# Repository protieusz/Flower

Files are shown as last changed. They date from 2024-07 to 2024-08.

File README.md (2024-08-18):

# Flower

PCBWay sponsored Flower, a variant of Noraneko42W, willow layout with 36 keys &amp; interchangeable trackball size.

# Featured In

https://kbd.news/Flower-2440.html

# Sponsorship

Thank you PCBWay for sponsoring my Flower PCB.  For all you PCB needs, you can always rely on PCBWay for all your PCB prototypes. Superb PCBA quality PCBs. No issues or scratches. Customer service very helpful and friendly. I highly recommend PCBWay for all your PCB prototype needs.

# Detailed Summary

Flower is a heavily modified version of Noraneko42W which has been blessed by darakuneko himself for the mod. Noraneko42 was originally designed by [darakuneko](https://github.com/darakuneko/Noraneko/tree/main/noraneko42w).

A List Of Mods Made To The Original SVG by darakuneko:

-Eliminate the extra 6th columns on each sides.

-A square hole was created in the middle that can accomodate either a 34mm or 25mm trackball powered by PMW3360 sensor.

-Base of the trackball holder with lens cut out is integrated into the top case with integrated 5mm switch plate. Top case sits flush with pcb.

-Full keyboard case was created to house the PCB.

-Created 2 versions of the PCB. Version 1 does not have hot swap and solder switches straight to the pcb which is currently been sponsored. Version 2 has hot swappable Kailh and will not be printed or tested in the future so print at your own risk.

-Flower is powered by RP2040 Core - A which you can get from AE.

-QMK code is borrowed from aki27 bally and modified the matrix to fit my Flower. No suppport will be given since I just copy and paste.

-3DP trackball holder is designed by @ma_po_daisuki and his designs are being sold at [his Booth store](https://ma-po.booth.pm/items/5258743) which cost around $10 cad. Go check it out and support him.

-Or you can use my STL 34mm version that is include on the above.

-Use M2 brass hot inserts 3.2mm diameter and 4mm length for the M2 screws to secure the case. I forgot how long is my M2 screws are but they should be greater than 10mm so estimated around 14.6mm. Play around with and buy multiple M2 lenght screws.

# Full Production Pics
















A219904D-366C-4CD2-A794-261117A48990
CCFA0EC4-57FF-48DE-BFDE-543125D1833C
491BFB59-66FD-417E-A977-1B71E1DFDC40
C8178070-97BA-4DCF-92F3-48E1E20A30CD
E05B9192-131A-4184-A84B-3BD31019660E
F3263E68-312A-4EAE-A6C8-C606E3723F1F
15B827F9-AF45-4CA4-89C8-4C4626D03518
571AE4CF-D7C3-4529-B977-25B417AD6DEA

# Rendering

Screenshot_2024-07-08_at_12 00 05_PM
Screenshot_2024-07-09_at_8 46 44_AM
Screenshot_2024-07-09_at_8 46 56_AM
Screenshot_2024-07-09_at_8 47 13_AM
Screenshot_2024-07-09_at_8 47 26_AM






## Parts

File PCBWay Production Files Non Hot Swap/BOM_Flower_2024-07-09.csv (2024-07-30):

ID | Name | Designator | Footprint | Quantity | Manufacturer Part | Manufacturer | Supplier | Supplier Part | Price | link
1 | PRTR5V0U2X,215 | D11 | SOT-143_L2.9-W1.3-P1.92-LS2.3-BR | 1 | PRTR5V0U2X,215 | Nexperia(安世) | LCSC | C12333 | 0.089 | https://item.szlcsc.com/280548.html
2 | BSMD0805-020-15V | F1 | F0805 | 1 | BSMD0805-020-15V | BHFUSE(佰宏) | LCSC | C883103 | 0.043 | https://item.szlcsc.com/343298.html
3 | RP2040-Core-A | U1 | RP2040-CORE-A | 1 |  |  |  |  |  |  | Omit do not pick.
4 | PMW3360DM-T2QU | U11 | PMW3360DM-T2QU.PACK | 1 | PMW3360DM-T2QU |  |  |  |  | http://www.pixart.com/upload/PMS0058-PMW3360DM-T2QU-NNDS-R1.30-06042016_20160902201411.pdf |  | Omit do not pick.
5 | TYPE-C-31-M-12 | USBC1 | USB-C_SMD-TYPE-C-31-M-12 | 1 | TYPE-C-31-M-12 | 韩国韩荣 | LCSC | C165948 | 0.163 | https://so.szlcsc.com/global.html?c=&k=C165948
6 | DIODE-SOD123 | D000,D001,D002,D003,D004,D005,D006,D007,D008,D009,D105,D106,D107,D108,D109,D205,D206,D207,D208,D209,D305,D306,D307,D100,D101,D102,D103,D104,D200,D201,D202,D203,D204,D302,D303,D304 | DIODE-SOD123 | 36
7 | 4.7uF | C17,C19,C20 | C0402 | 3 | CL05A475MP5NRNC | SAMSUNG(三星) | LCSC | C23733 | 0.005 | https://lcsc.com/eda_search?q=C23733&%26type=1&ref=editor
8 | 100nF | C18 | C0402 | 1 | CL05B104KB54PNC | SAMSUNG(三星) | LCSC | C307331 | 0.005 | https://lcsc.com/eda_search?q=C307331&%26type=1&ref=editor
9 | 5.1kΩ | R1,R2 | R0402 | 2 | 0402WGF5101TCE | UNI-ROYAL(厚声) | LCSC | C25905 | 0.001 | https://item.szlcsc.com/323315.html
10 | 10kΩ | R10,R12,R13 | R0402 | 3 | 0402WGF1002TCE | UNI-ROYAL(厚声) | LCSC | C25744 | 0.001 | https://lcsc.com/eda_search?q=C25744&%26type=1&ref=editor
11 | 39Ω | R11 | R0402 | 1 | 0402WGJ0390TCE | UNI-ROYAL(厚声) | LCSC | C25164 |  | https://lcsc.com/eda_search?q=C25164&%26type=1&ref=editor
12 | 15kΩ | R14 | R0402 | 1 | 0402WGF1502TCE | UNI-ROYAL(厚声) | LCSC | C25756 | 0.001 | https://lcsc.com/eda_search?q=C25756&%26type=1&ref=editor
13 | AP2127K-ADJTRG1 | U10 | SOT-23-5_L3.0-W1.7-P0.95-LS2.8-BR | 1 | AP2127K-ADJTRG1 | DIODES(美台) | LCSC | C96343 | 0.072 | https://lcsc.com/eda_search?q=C96343&%26type=1&ref=editor
14 | Switch | K000,K001,K002,K003,K004,K005,K006,K007,K008,K009,K100,K101,K102,K103,K104,K105,K106,K107,K108,K109,K200,K201,K202,K203,K204,K205,K206,K207,K208,K209,K302,K303,K304,K305,K306,K307 | CHERRY_MX_100_MILLMAX | 36 |  |  |  |  |  |  | Omit do not pick.

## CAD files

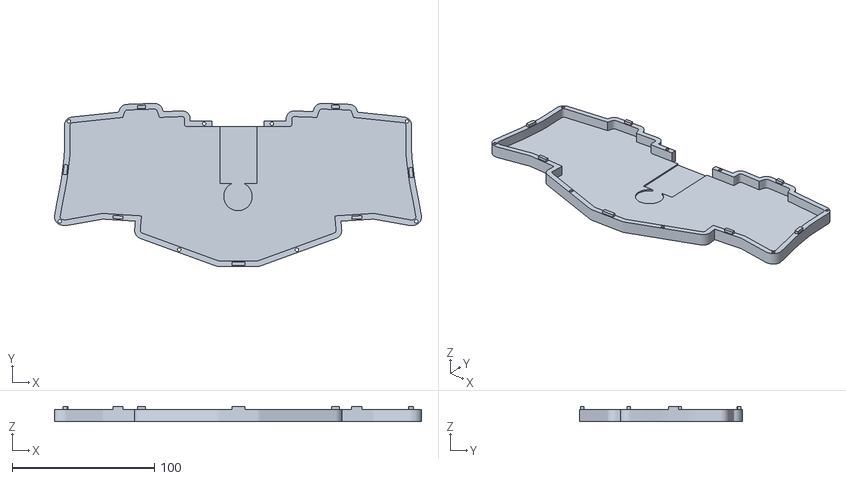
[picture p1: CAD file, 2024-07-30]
STLs/Flower Bottom.stl
258.0 x 114.7 x 10.6

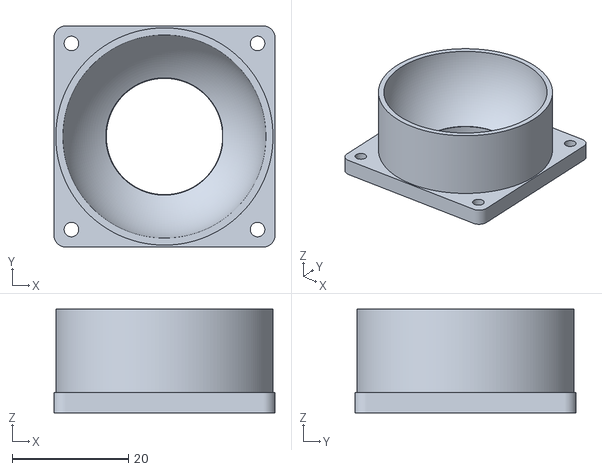
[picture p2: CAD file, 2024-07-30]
Trackball35mm.stl
38.0 x 38.0 x 17.8

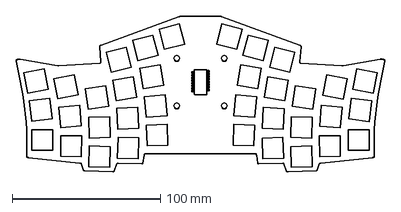
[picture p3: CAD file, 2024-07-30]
Lotus PCF 2.0.dxf
248.1 x 104.8 mm

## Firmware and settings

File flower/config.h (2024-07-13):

// Copyright 2024 ProtieusKeebs
// SPDX-License-Identifier: GPL-2.0-or-later

#pragma once

//#define VIAL_KEYBOARD_UID {0xC4, 0x18, 0xCC, 0x6D, 0x1C, 0x16, 0x5B, 0x8D}
//#define VIAL_UNLOCK_COMBO_ROWS {0, 0}
//#define VIAL_UNLOCK_COMBO_COLS {1, 11}

/* VIA */
//#define DYNAMIC_KEYMAP_LAYER_COUNT 8


/* key matrix size */
//#define MATRIX_COLS 13
//#define MATRIX_ROWS 4


/* tapping term */
// #define TAPPING_FORCE_HOLD
//#define TAPPING_TERM 200
// #define IGNORE_MOD_TAP_INTERRUPT

#define RP2040_BOOTLOADER_DOUBLE_TAP_RESET // Activates the double-tap behavior
#define RP2040_BOOTLOADER_DOUBLE_TAP_RESET_TIMEOUT 200U // Timeout window in ms in which the double tap can occur.

#ifdef COMBO_ENABLE
#    define COMBO_COUNT 2
#    define COMBO_TERM 200
#endif

/* Encoder */
//#define ENCODERS_PAD_A { GP11 }
//#define ENCODERS_PAD_B { GP12 }
//#define ENCODER_RESOLUTION 4

/* Matrix*/
//#define MATRIX_COL_PINS { GP25, GP24, GP23, GP22, GP21, GP26, GP27, GP20, GP19, GP18, GP17, GP16, GP13 }
//#define MATRIX_ROW_PINS { GP28, GP10, GP14, GP15 }

/* COL2ROW, ROW2COL */
//#define DIODE_DIRECTION COL2ROW


/* Set 0 if debouncing isn't needed */
//#define DEBOUNCE 5


/* Mechanical locking support. Use KC_LCAP, KC_LNUM or KC_LSCR instead in keymap (Very Important for Scroll Lock!!!) */
#undef LOCKING_SUPPORT_ENABLE
/* Locking resynchronize hack */
#undef LOCKING_RESYNC_ENABLE


/* Trackball */

#ifdef POINTING_DEVICE_ENABLE

//#    undef RP_SPI_USE_SPI0
//#    define RP_SPI_USE_SPI0 TRUE
//#    undef RP_SPI_USE_SPI1
//#    define RP_SPI_USE_SPI1 FALSE
#    define SPI_DRIVER SPID1

//#    define SPI_SCK_PIN GP22 //6
//#    define SPI_MISO_PIN GP24 //4
//#    define SPI_MOSI_PIN GP23 //7
#    define SPI_SCK_PIN GP14
#    define SPI_MISO_PIN GP12
#    define SPI_MOSI_PIN GP15

#endif


#ifndef PMW33XX_CS_PIN
#    define PMW33XX_CS_PIN GP13
#endif
#define POINTING_DEVICE_INVERT_X
#define POINTING_DEVICE_INVERT_Y
//#define ROTATIONAL_TRANSFORM_ANGLE 90
#define POINTING_DEVICE_ROTATION_180

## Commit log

2024-07-30 Gerber Non Hot Swap version
    [BOM_Flower_2024-07-09.csv, PickAndPlace_PCB_Flower_2024-07-09.csv]
2024-07-30 Hot swap version
    [BOM_Flower-Hot-Swap-Edition_2024-07-12.csv, PickAndPlace_PCB_Flower-Hot-Swap-Edition_2024-07-12.csv]
2024-07-30 PCB DXF
    [Lotus PCF 2.0.dxf]
2024-07-30 35mm Trackball holder
    [Trackball35mm.stl]
